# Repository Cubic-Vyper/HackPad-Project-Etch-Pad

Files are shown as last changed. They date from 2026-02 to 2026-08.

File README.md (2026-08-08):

# HackPad-Project-Etch-Pad
This is my repository for my Hackpad called "Etch-Pad".
This HackPad has two layers. In the first, the rotary encoders control the mouse like an Etch-n-Sketch, and the switchs have some useful macros. On the second layer the rotary encoders control volume and led brightness, and the switches have some useful macros.

Blueprint Page:https://blueprint.hackclub.com/projects/10732

Buttons:
Layer 0: Screenshot, Paste, Parrot, Space

Layer 1: Previous track, Play/Pause+RickRoll, Next track, Spam E

Encoders:
Layer 0: Mouse control

Layer 1: Volume control + Led brightness

Parts Used:

Seeed XIAO RP2040

4x MX-Style switches

2x EC11 Rotary encoders

4x white blank DSA keycaps

4x SK6812 MINI-E LEDs

4x M3x16mm screws

4x M3x5mx4mm heatset inserts

____________________________________________________________________________________________________

This is the assembled model of my hackpad and what it should look like:





Schematic Screenshot:



PCB Screenshot:



to assemble the case, first collect all of your parts:



next insert the assembled PCB into the bottem half of the case:



then place the top plate on and screw it together:





finnaly attach the keycaps and the enchoder knobs:



plug it up:



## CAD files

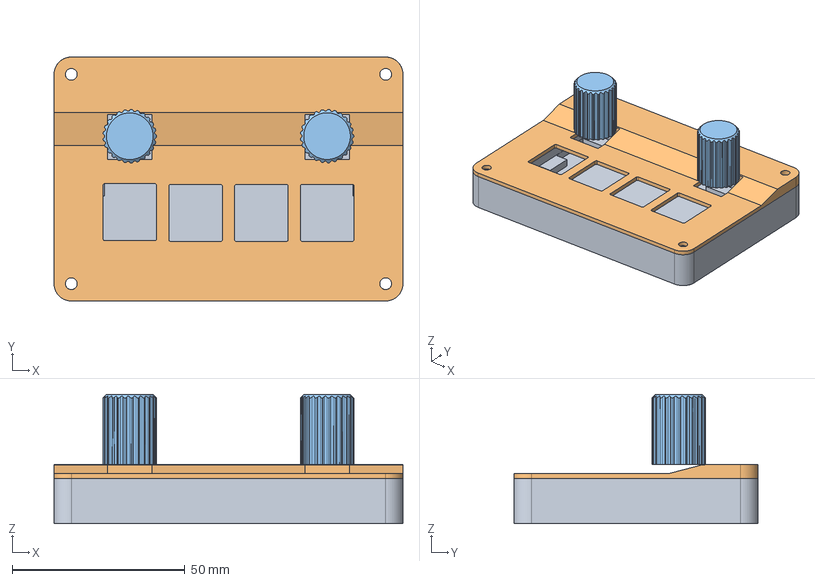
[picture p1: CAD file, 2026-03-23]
CAD/EtchPad_Case.step
101.0 x 70.6 x 37.4 mm
EtchPad
EtchPad_Case_Top
Enchoder knob

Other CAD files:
CAD/EtchPad_Case.3mf

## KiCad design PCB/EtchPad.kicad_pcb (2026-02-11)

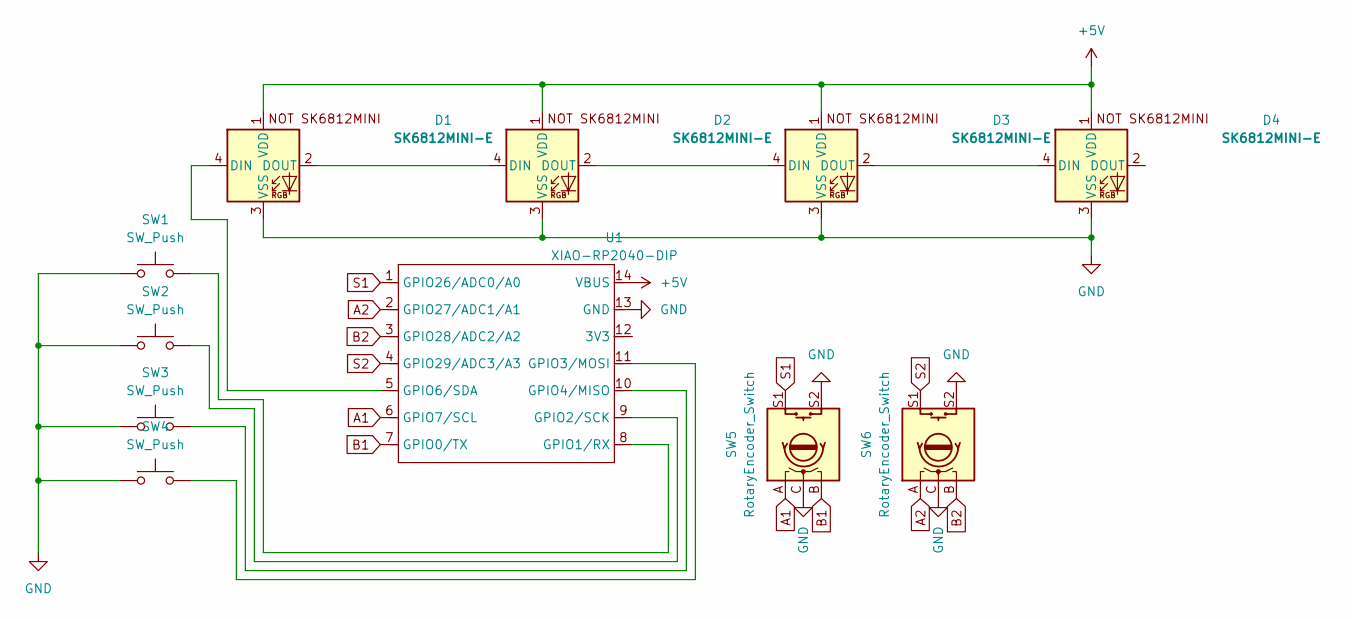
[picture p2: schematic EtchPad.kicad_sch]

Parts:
D1, D2, D3, D4: SK6812MINI-E; SK6812MINI-E_fixed
SW1, SW2, SW3, SW4: SW_Push; SW_Cherry_MX_1.00u_PCB
SW5, SW6: RotaryEncoder_Switch; RotaryEncoder_Alps_EC11E-Switch_Vertical_H20mm
U1: XIAO-RP2040-DIP

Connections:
+5V: D1.1 (VDD), D2.1 (VDD), D3.1 (VDD), D4.1 (VDD), U1.14 (VBUS)
A1: SW5.A, U1.6 (GPIO7/SCL)
A2: SW6.A, U1.2 (GPIO27/ADC1/A1)
B1: SW5.B, U1.7 (GPIO0/TX)
B2: SW6.B, U1.3 (GPIO28/ADC2/A2)
GND: D1.3 (VSS), D2.3 (VSS), D3.3 (VSS), D4.3 (VSS), SW1.1, SW2.1, SW3.1, SW4.1, SW5.C, SW5.S2, SW6.C, SW6.S2, U1.13 (GND)
unnamed: D1.4 (DIN), U1.5 (GPIO6/SDA)
unnamed: D1.2 (DOUT), D2.4 (DIN)
unnamed: D2.2 (DOUT), D3.4 (DIN)
unnamed: D3.2 (DOUT), D4.4 (DIN)
unnamed: SW1.2, U1.8 (GPIO1/RX)
unnamed: SW2.2, U1.9 (GPIO2/SCK)
unnamed: SW4.2, U1.11 (GPIO3/MOSI)
unnamed: SW3.2, U1.10 (GPIO4/MISO)
S1: SW5.S1, U1.1 (GPIO26/ADC0/A0)
S2: SW6.S1, U1.4 (GPIO29/ADC3/A3)

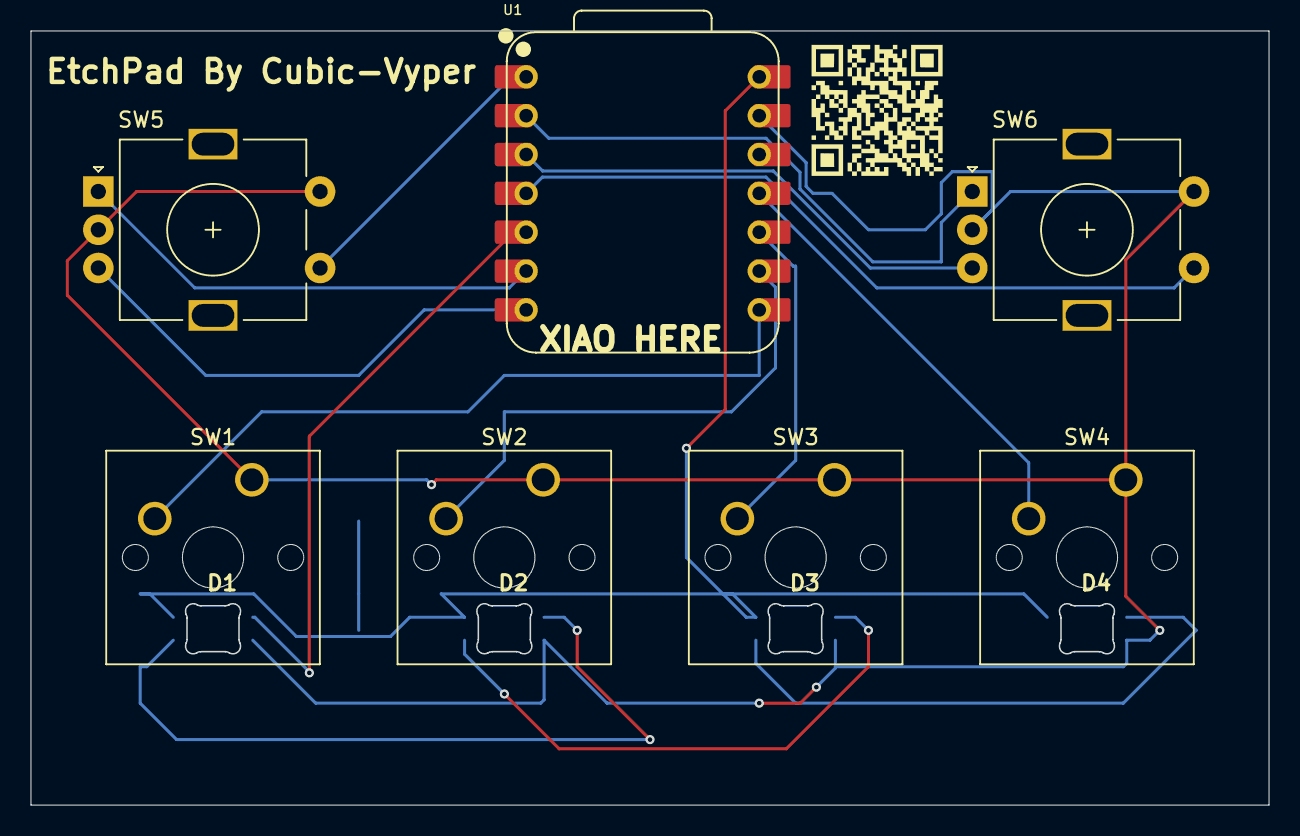
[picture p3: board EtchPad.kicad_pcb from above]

Board: 2 copper layers, 81.0 x 50.6 mm, 11 parts (0 on the bottom side), 16 nets.

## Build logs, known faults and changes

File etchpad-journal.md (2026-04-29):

<!--
  This journal is auto generated by Hack Club Blueprint.
-->

# 2/23/2026 - Code debuging and flashing code  

_Time spent: 8.0h_  

So I added circuitpython and kmk to my keyboard, when I added my code, I received a few errors. I had to relabel some pins in my code. Then my code corupted and I spent hours trying all kinds of trouble shooting, in the end I had to reset my computer and nuke the Xiao (a few times 🙃). I also had to switch to putting my code in code.py instead of boot.py, the code would run before it's finished setting up.



Switches 
board.GP1 → board.D7

board.GP2 → board.D8

board.GP4 → board.D9

board.GP3 → board.D10

Encoder 1
board.GP9 → board.D6

board.GP0 → board.D7

board.GP26 → board.A0

Encoder 2
board.GP27 → board.D1

board.GP28 → board.D2

board.GP29 → board.D3

# 3/16/2026 11:28 AM - Soldering  

_Time spent: 1.5h_  

First before I stared to solder I made larger cutouts on the bottom of the switches using a file and a knife (to let more light from the leds pass through) 



next I set up my soldering station



while soldering I killed 3 led because I was using the wrong tip on my soldering iron, while removing one of those leds, I somehow removed 2 soldering pads for a led, so I grabbed some wire and soldered the led to where it should go. 



at first I had no idea I had destroed the soldering pads and whent to use it and only the first two would light up, after a bit I finaly found out what I did.

next I shortened the pin headers now that I had soldered them 



now everything worked



exept my previous/play/pause keys in my second layer. I reseted it and now it works? I have no idea how this happened, but if it works it works.  

# 3/16/2026 11:33 AM - fixing the top plate  

_Time spent: 2.3h_  

so I went to put my soldered pcb in its case, I didn't plan on there being spacers under the xioa, so now the lid won't fit, if I raise the lid anymore the keys won't work, so I started brain storming and decided to add a slant after the keys so there will be enogh room for the xiao and it still look nice.

so now I start designing, first I made a sketch of where the slant will be



now I make another but on the side



the big rectangle is me making sure that my enchoder knob will fit (I'll show that later), at first I was gonna do a slant all the way to the edge



but instead I did a slant just to the hight I need



now I cutout the holes for the parts agin



and now the area for the xiao



Now that there is more hieght I will need a longer screw, luckily I have a lot of M3 screws so that won't be a problem.

now I design the enchoder knob I mentiond above first I measure the shaft of the enchoder and schetc it



next from that scetch I extrude the top 



then the D-shaft part 



and then the last part (this covers most of the threads) 



now I add a chanfer aroung the top 



then I extrude a grove into the knob



and repeat it with pattern 



now I round the edges of each cutout (I found out that I could do this before the pattern, but not before I hand selected all of those groves 😭)



now I add it to my assembled model



next I will print these out.

I use cura slicer 



I want to use ironing on the top layers but not the slant, to do this I will slice it where it irons everything, but have it pause after the lower section of it, next I turn it to only ironing the highest layer, with the same pause. next I open the gcode and I delete evrything after the pause in the first one (my print can't resume after pause so I have to edit gcode to resume as another file). 



then I edit the first to resume the rest of the gcode with the new setting (I delete the every thing expet the startup code before the pause).



now I print  

# 3/16/2026 11:35 AM - Aassembling The Case  

_Time spent: 0.2h_  

now that I have all my parts printed it's time to assemble



first I insert the pcb into the bottem half of the case



next I put the top on



now I screw it all together



Finaly I add the keycaps and the enchoder knobs!



now I plug it up



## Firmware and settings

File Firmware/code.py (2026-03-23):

import time
import board
from kmk.kmk_keyboard import KMKKeyboard
from kmk.scanners.keypad import KeysScanner
from kmk.keys import KC
from kmk.modules.macros import Press, Release, Tap, Macros
from kmk.modules.layers import Layers
from kmk.modules.encoder import EncoderHandler
from kmk.modules.holdtap import HoldTap
from kmk.modules.mouse_keys import MouseKeys
from kmk.modules.rapidfire import RapidFire
from kmk.modules import Module
from kmk.extensions.RGB import RGB, AnimationModes
from kmk.extensions.media_keys import MediaKeys
from kmk.extensions import Extension


time.sleep(1.5)

keyboard = KMKKeyboard()

# RGB
rgb = RGB(
    pixel_pin=board.D4 ,
    num_pixels=4,
    val_limit=100,
    hue_default=0,
    sat_default=255,
    val_default=50,
    animation_mode=AnimationModes.RAINBOW,
    animation_speed=5,
    rgb_order=(1, 0, 2),
)

# Layer RGB indicators
class LayerRGBMode(Extension):
    def __init__(self, rgb):
        self.rgb = rgb
        self.current_layer = None
    
    def on_runtime_enable(self, keyboard):
        return
    
    def on_runtime_disable(self, keyboard):
        return
    
    def during_bootup(self, keyboard):
        return
    
    def before_matrix_scan(self, keyboard):
        # Check for layer changes before scanning keys
        if keyboard.active_layers:
            new_layer = keyboard.active_layers[0]
        else:
            new_layer = 0

        if new_layer != self.current_layer:
            self.current_layer = new_layer
            self.update_rgb_mode()
    
    def after_matrix_scan(self, keyboard):
        # Also check after scanning to catch any changes
        pass
    
    def before_hid_send(self, keyboard):
        pass
    
    def after_hid_send(self, keyboard):
        pass
    
    def on_powersave_enable(self, keyboard):
        pass
    
    def on_powersave_disable(self, keyboard):
        pass
    
    def update_rgb_mode(self):
        if self.current_layer == 0:
            # Layer 0: Rainbow
            self.rgb.animation_mode = AnimationModes.RAINBOW
        else:
            # Layer 1: Swirl
            self.rgb.animation_mode = AnimationModes.SWIRL
        self.rgb.show()


# Modules
layer_rgb_mode = LayerRGBMode(rgb)
macros = Macros()
layers = Layers()
holdtap = HoldTap()
holdtap.tap_time = 1250  # 1.25 seconds
encoder_handler = EncoderHandler()
mouse_keys = MouseKeys()
rapidfire = RapidFire()



keyboard.modules = [rapidfire, layers, holdtap, encoder_handler, macros, mouse_keys, layer_rgb_mode]
keyboard.extensions.append(MediaKeys())
keyboard.extensions.append(rgb)
keyboard.extensions.append(layer_rgb_mode)

# Custom keys
SPAM_CLICK = KC.RF(
    KC.MB_LMB, 
    timeout=200, 
    interval=70, 
    enable_interval_randomization=True, 
    randomization_magnitude=25, 
    toggle=True
)

SCREENSHOT = KC.MACRO(
    Press(KC.LWIN), 
    Press(KC.LSFT), 
    Tap(KC.S), 
    Release(KC.LSFT), 
    Release(KC.LWIN)
)

RICKROLL = KC.MACRO(
    # Open Run dialog
    Press(KC.LWIN), Tap(KC.R), Release(KC.LWIN), 1500,
    # Type cmd and press enter
    Tap(KC.C), Tap(KC.M), Tap(KC.D), Tap(KC.ENTER), 2500,
    # Type the command
    Tap(KC.C), Tap(KC.U), Tap(KC.R), Tap(KC.L), Tap(KC.SPACE), Tap(KC.A), Tap(KC.S),
    Tap(KC.C), Tap(KC.I), Tap(KC.I), Tap(KC.DOT), Tap(KC.L), Tap(KC.I), Tap(KC.V), Tap(KC.E),
    Tap(KC.SLASH), Tap(KC.R), Tap(KC.I), Tap(KC.C), Tap(KC.K), Tap(KC.ENTER), Tap(KC.F11)
)

PARROT = KC.MACRO(
    # Open Run dialog
    Press(KC.LWIN), Tap(KC.R), Release(KC.LWIN), 1500,
    # Type cmd and press enter
    Tap(KC.C), Tap(KC.M), Tap(KC.D), Tap(KC.ENTER), 2500,
    # Type the command
    Tap(KC.C), Tap(KC.U), Tap(KC.R), Tap(KC.L), Tap(KC.SPACE), Tap(KC.P), Tap(KC.A), Tap(KC.R), Tap(KC.R),
    Tap(KC.O), Tap(KC.T), Tap(KC.DOT), Tap(KC.L), Tap(KC.I), Tap(KC.V), Tap(KC.E), Tap(KC.ENTER)
)

HACK = KC.MACRO(
    # Open Run dialog
    Press(KC.LWIN), Tap(KC.R), Release(KC.LWIN), 1500,
    # Type cmd and press enter
    Tap(KC.C), Tap(KC.M), Tap(KC.D), Tap(KC.ENTER), 2500,
    # Type the command
    Tap(KC.C), Tap(KC.O), Tap(KC.L), Tap(KC.O), Tap(KC.R), Tap(KC.SPACE), Tap(KC.N2),
    Tap(KC.ENTER), 600, Tap(KC.D), Tap(KC.I), Tap(KC.R), Tap(KC.SLASH), Tap(KC.S), Tap(KC.ENTER), Tap(KC.F11)
)

PASTE = KC.MACRO(
    Press(KC.LCTL), 
    Tap(KC.V), 
    Release(KC.LCTL)
)

# Define pins
PINS = [board.D7, board.D8, board.D9, board.D10] 

# Tell kmk we are not using a key matrix
keyboard.matrix = KeysScanner(
    pins=PINS,
    value_when_pressed=False,
)

# Encoder pins
encoder_handler.pins = (
    (board.D5, board.D6, board.D0),   # First encoder
    (board.D1, board.D2, board.D3),   # Second encoder
)


encoder_handler.encoder_debounce = 30  # Reduces duplicate signals

encoder_handler.divisor = 2 

# Define encoder actions 
encoder_handler.map = [
    # Layer 0 - Mouse control
    [
        (KC.MS_RIGHT, KC.MS_LEFT, KC.MB_LMB, 50), #scrol (KC.MW_UP, KC.MW_DN, KC.MB_LMB, 50),
        (KC.MS_UP, KC.MS_DOWN, KC.MB_RMB, 50),
    ],
    # Layer 1 - Volume + RGB control
    [
        (KC.VOLU, KC.VOLD, KC.MUTE),
        (KC.RGB_VAI, KC.RGB_VAD, HACK),
    ],
]

# define the button pins
keyboard.keymap =    [
    # Layer 0
    [
        KC.HT(SCREENSHOT, KC.TO(1)),           # Tap: Screenshot, Hold: Layer 1
        PASTE,                                   # Paste macro
        PARROT,                                  # Parrot macro
        KC.SPACE,                                # Space
    ],
    # Layer 1
    [
        KC.HT(KC.MPRV, KC.TO(0)),               # Tap: Previous track, Hold: Layer 0
        KC.HT(KC.MPLY, RICKROLL),                # Tap: Play/Pause, Hold: Rickroll
        KC.HT(KC.MNXT, KC.F11),                                  # Next track
        SPAM_CLICK,                                   # Spam left click
    ],
]

# Start kmk
if __name__ == '__main__':
    keyboard.go()
